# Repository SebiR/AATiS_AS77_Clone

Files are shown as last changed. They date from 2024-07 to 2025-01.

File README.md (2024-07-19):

# AATiS DCF77 Empfänger

This is a clone of the original AATiS AS77 DCF77 Receiver board.

This project was the very first electronic kit that I assembled when I was eleven or twelve years old and it basically started my career as an EE.\
The receiver I built back then still functions to this day and as the design itself celebrates its 30th birthday in this year, I wanted to preserve it for generations to come as the original PCB has been discontinued.

This is a really great project for beginners to learn soldering and learn something about analog circuits and DCF77.



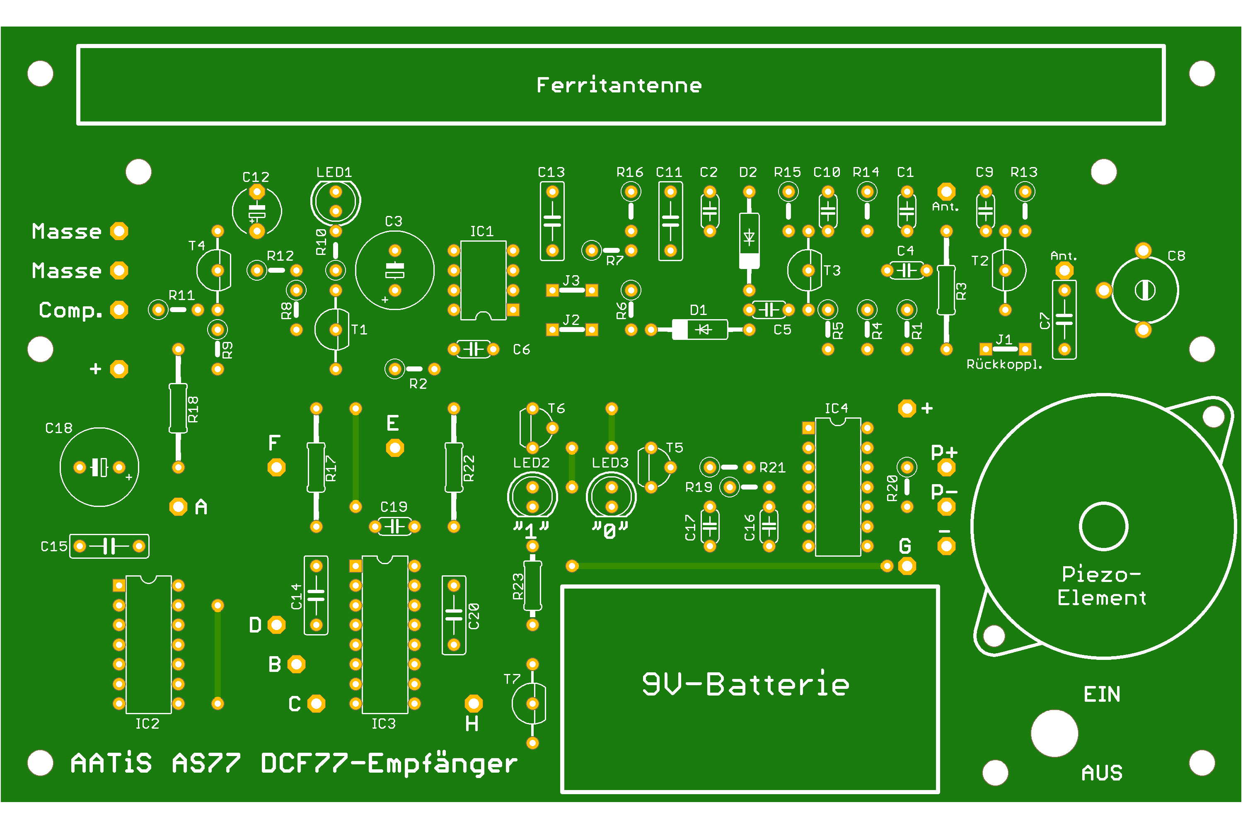
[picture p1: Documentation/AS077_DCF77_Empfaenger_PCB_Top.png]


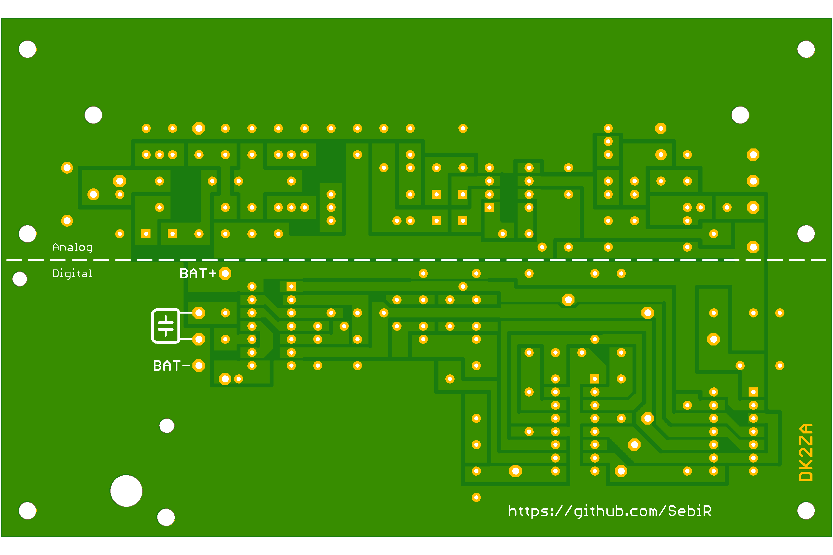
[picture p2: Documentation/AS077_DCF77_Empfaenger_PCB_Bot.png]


## Description

* Mechanical 99.9% identical to the original board
* Layout 99.9% identical to original layout

In case you're wondering: The layout looks a bit strange, but I think it was designed with a really simple CAD software in 1994.
But the layout is great if you want to etch the PCB yourself!

## Status Quo
* Layout basically finished
* Schematic still a mess
* Library needs cleaning up

## Disclaimer
> [!CAUTION]
> This project was created to archive and preserve the DCF77 receiver. AATis/Helmut Pape own all the rights to this design.
> There's no copyright infringement intended, please contact me for removal.

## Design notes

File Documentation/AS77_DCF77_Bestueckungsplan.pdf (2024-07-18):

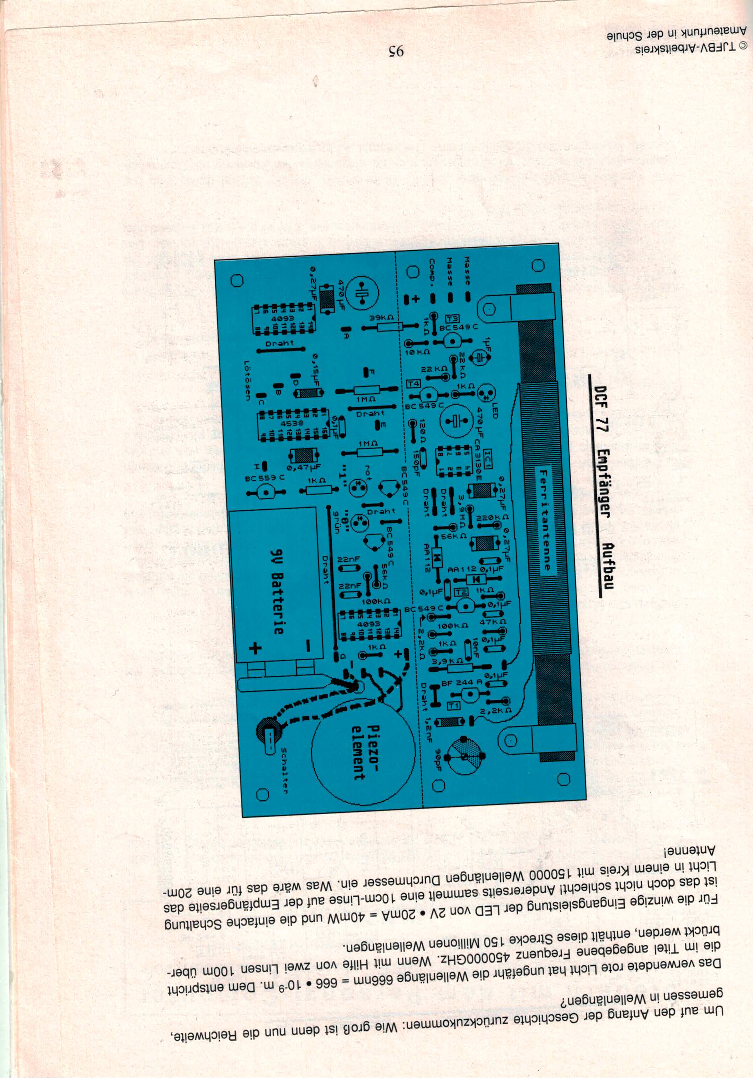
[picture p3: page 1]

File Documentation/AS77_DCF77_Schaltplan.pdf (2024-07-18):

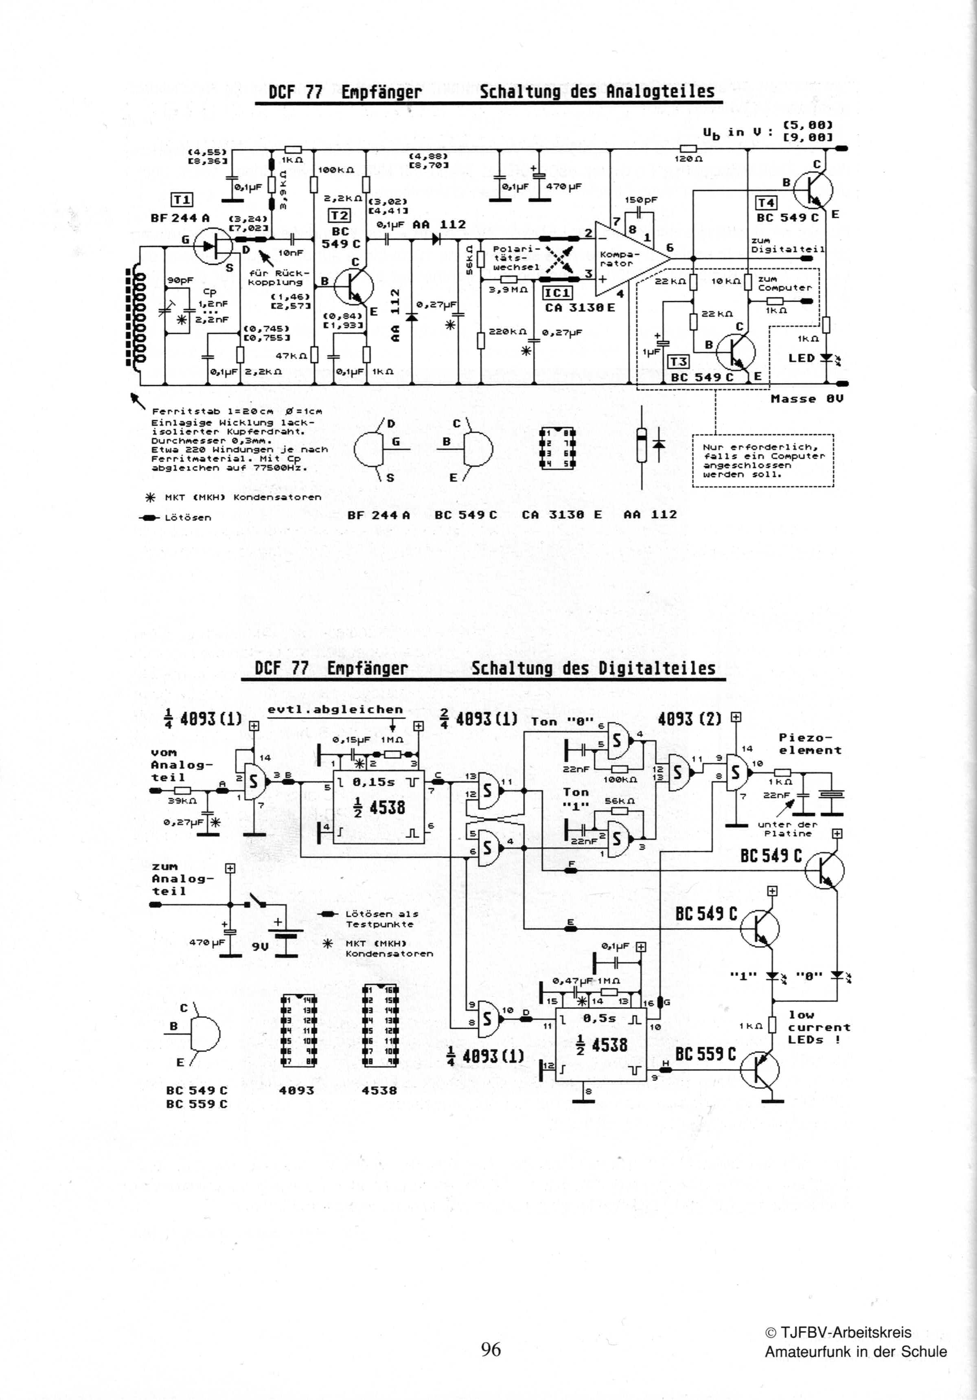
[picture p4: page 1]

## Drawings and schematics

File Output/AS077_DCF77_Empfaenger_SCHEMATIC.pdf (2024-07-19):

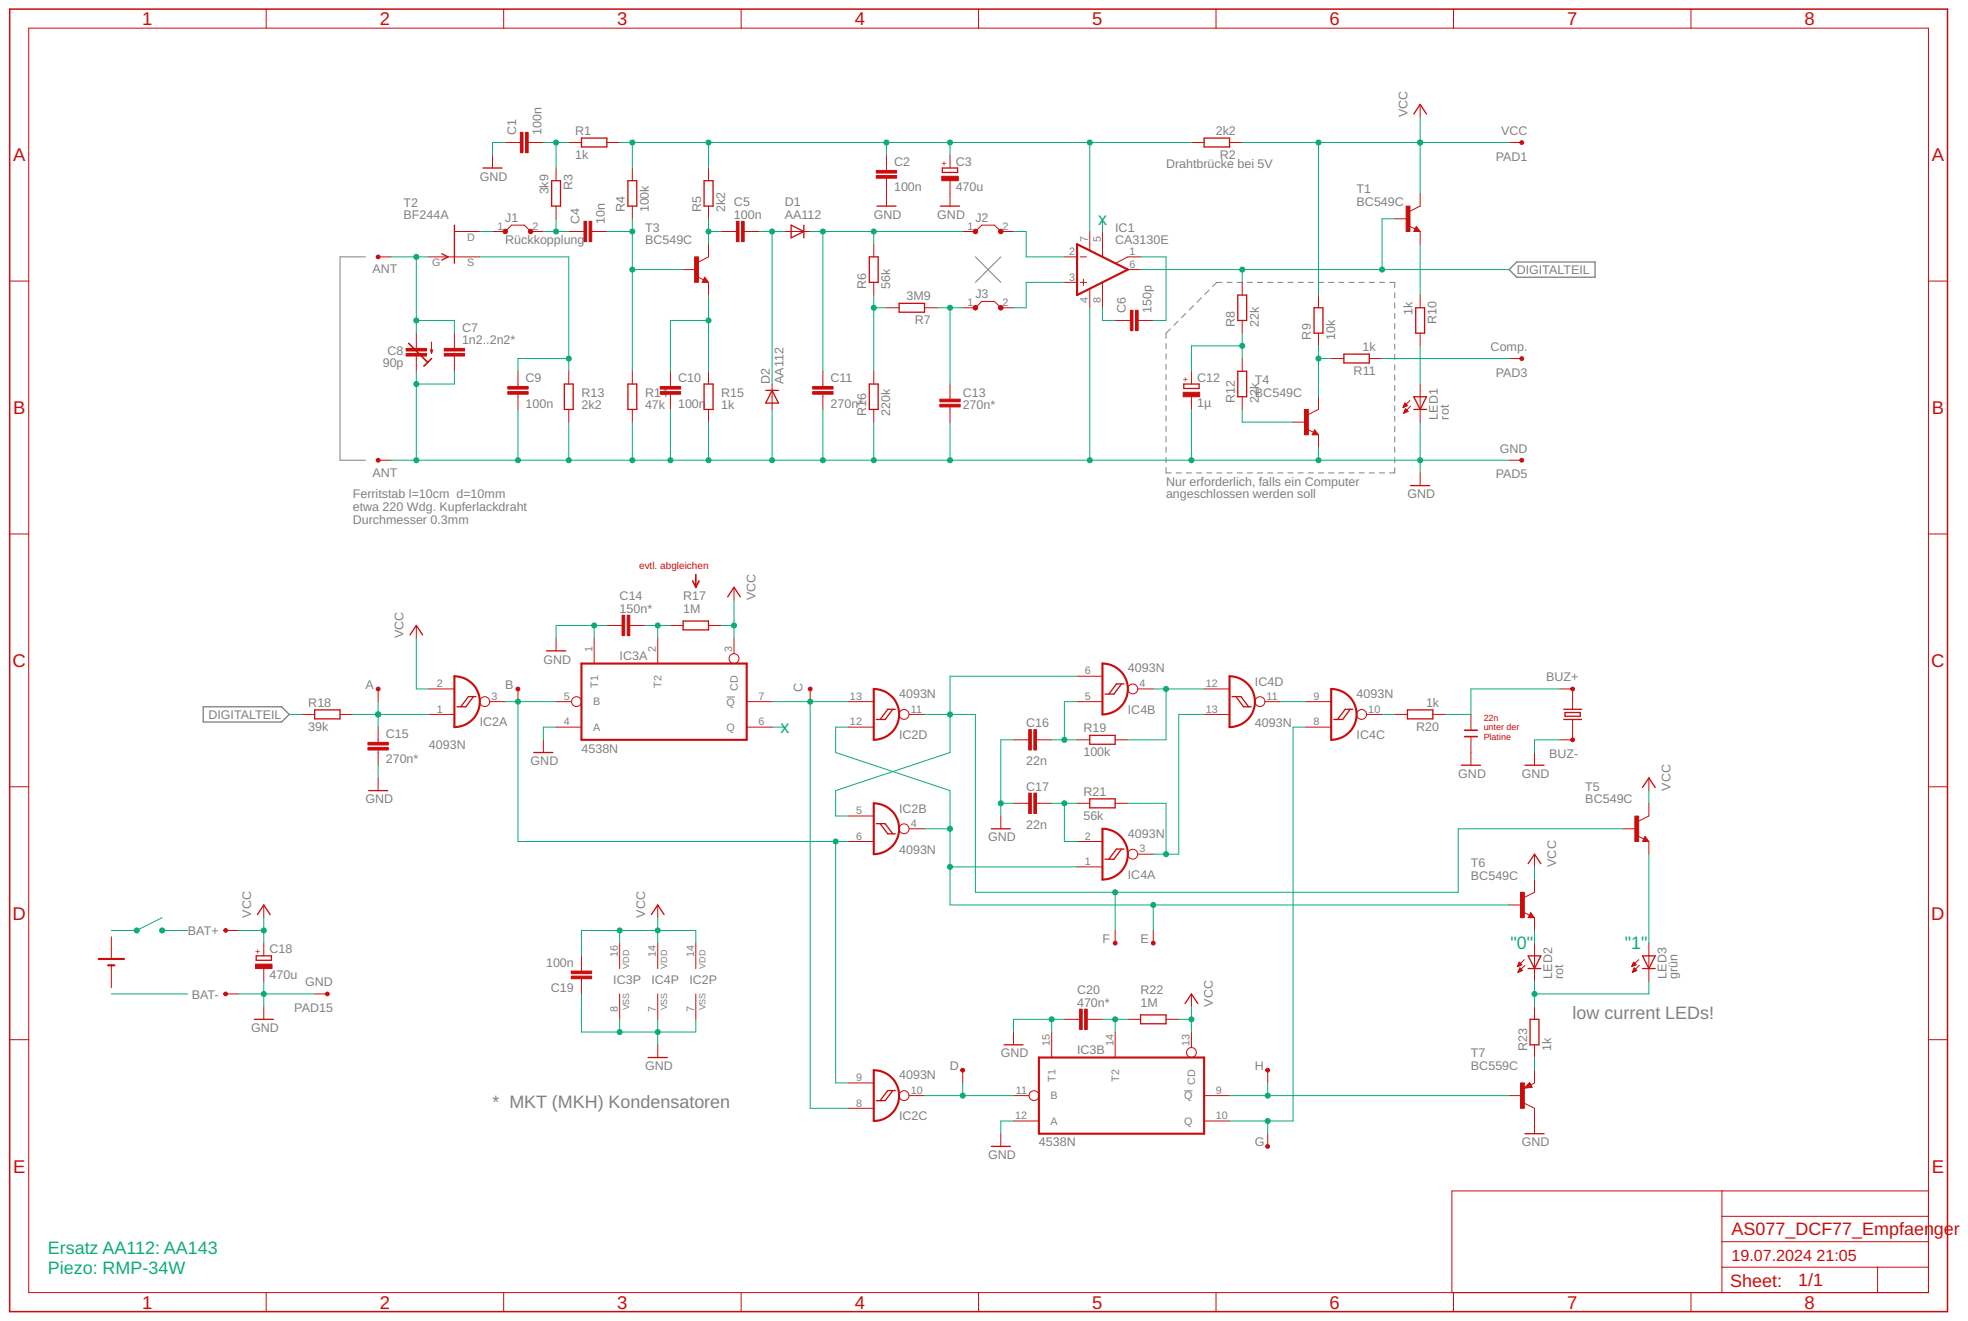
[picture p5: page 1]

ANT
Nur erforderlich, falls ein Computer Ferritstab l=10cm d=10mm

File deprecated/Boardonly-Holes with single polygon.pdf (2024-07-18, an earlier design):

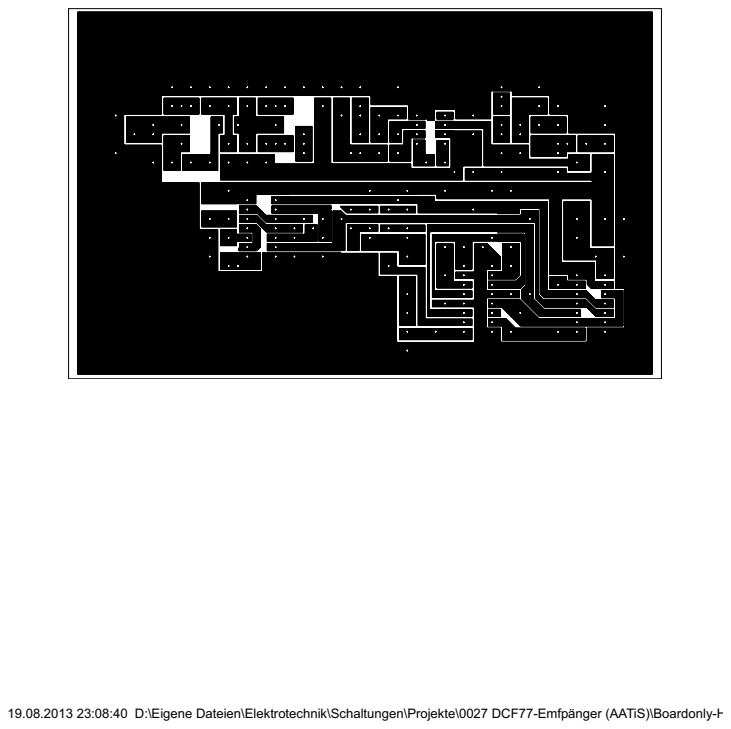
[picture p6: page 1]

19.08.2013 23:08:40 D:\Eigene Dateien\Elektrotechnik\Schaltungen\Projekte\0027 DCF77-Emfpänger (AATiS)\Boardonly-Holes with single polygon.brd

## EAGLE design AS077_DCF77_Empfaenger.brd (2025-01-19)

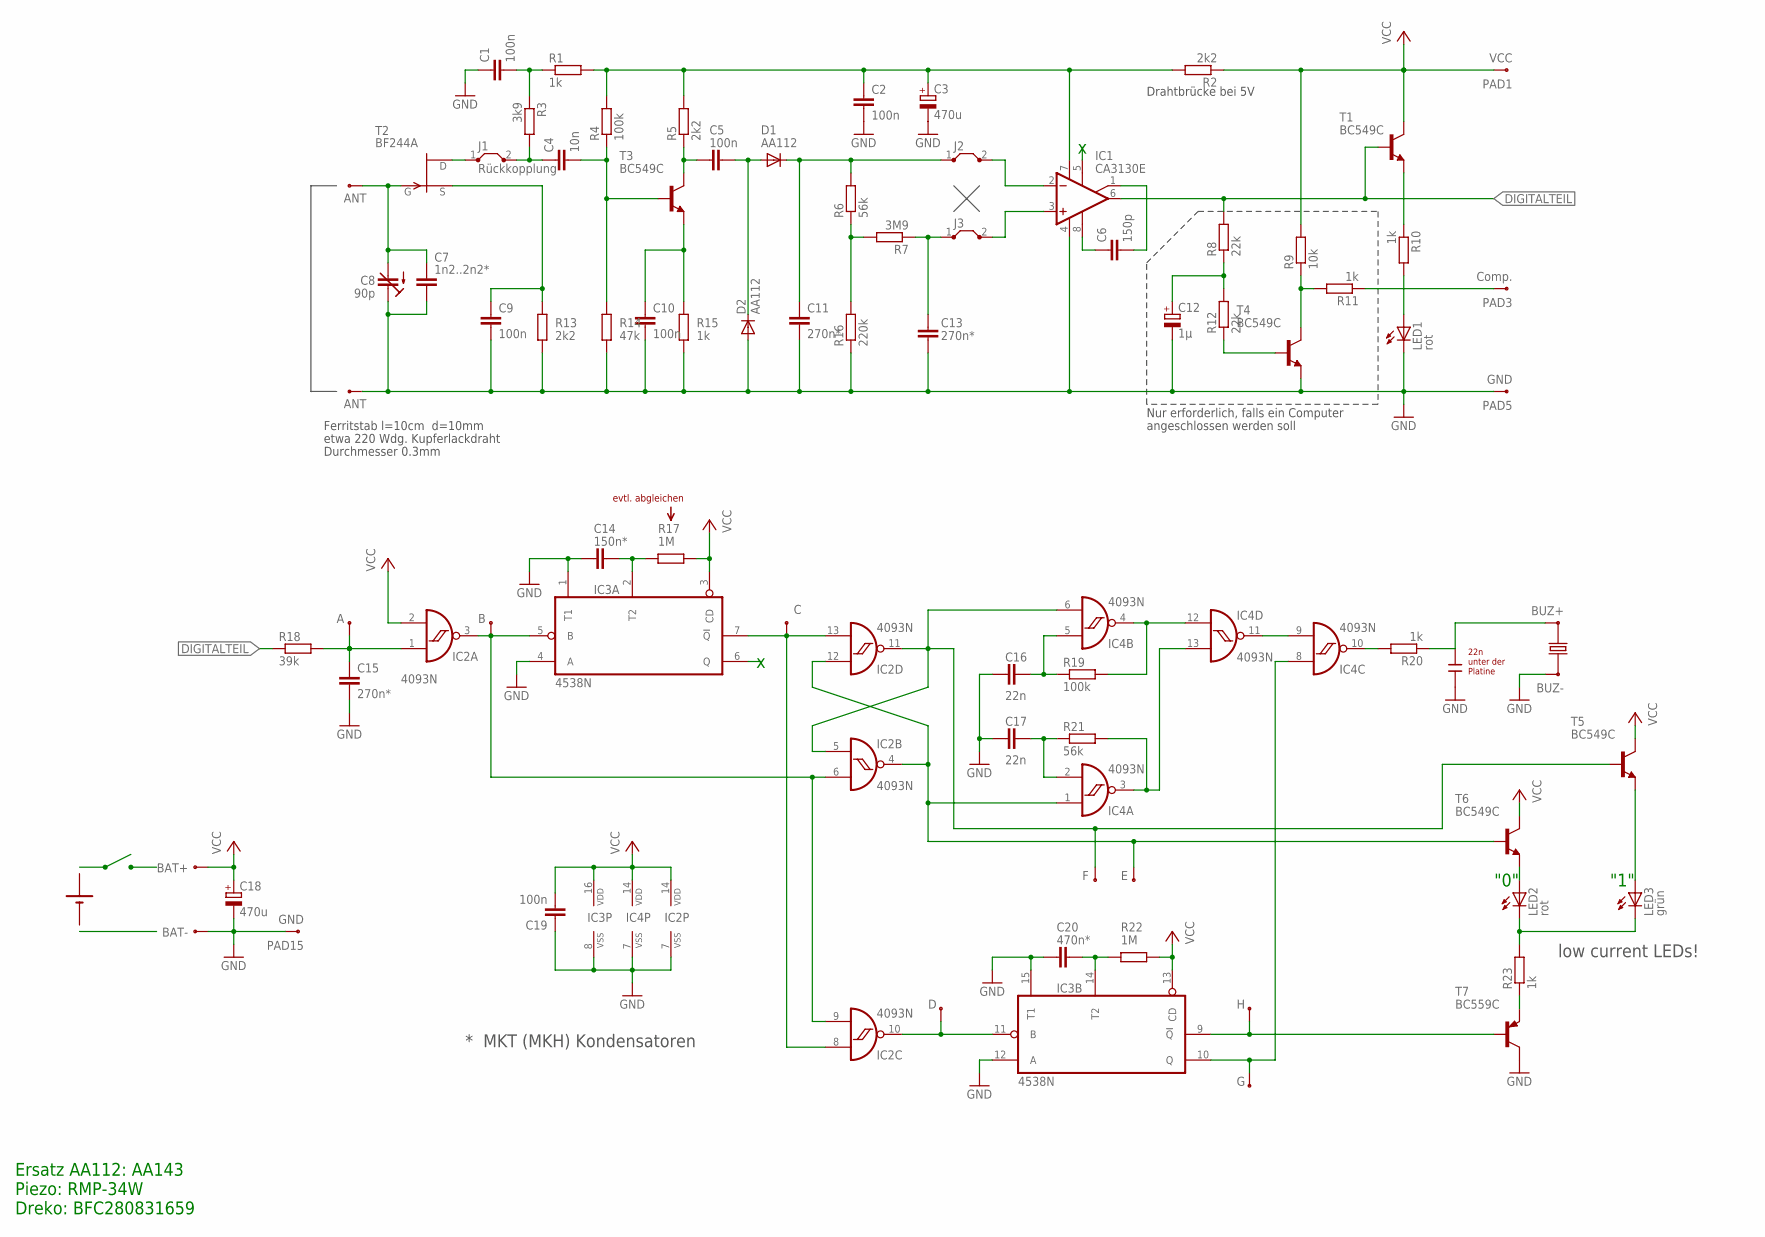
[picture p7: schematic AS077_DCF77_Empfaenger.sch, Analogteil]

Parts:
C1, C2, C5, C9, C10, C19: 100n; RCL_C050-024X044
C3, C18: 470u; RCL_E5-10,5
C4: 10n; RCL_C050-024X044
C6: 150p; RCL_C050-024X044
C7: 1n2..2n2*; RCL_C075-032X103
C8: 90p; RCL_CTRIM808-BC7.5
C11, C13, C15: 270n*; RCL_C075-032X103
C12: 1µ; E5-6
C14: 150n*; RCL_C075-032X103
C16, C17: 22n; RCL_C050-024X044
C20: 470n*; RCL_C075-032X103
D1, D2: AA112; DIODE_DO07
IC1: CA3130E; DIL08
IC2, IC4: 4093N; DIL14
IC3: 4538N; DIL16
J1: Rückkopplung; JUMPER_05
J2, J3: JUMPER_J5MM; JUMPER_05
LED1, LED2: rot; LED_LED5MM
LED3: grün; LED_LED5MM
PAD1: VCC; WIREPAD_2.2/1.3
PAD2, PAD4: ANT; WIREPAD_2.2/1.3
PAD3: Comp.; WIREPAD_2.2/1.3
PAD5, PAD15: GND; WIREPAD_2.2/1.3
PAD6: A; WIREPAD_2.2/1.3
PAD7: B; WIREPAD_2.2/1.3
PAD8: C; WIREPAD_2.2/1.3
PAD9: BUZ-; WIREPAD_2.2/1.3
PAD10: BUZ+; WIREPAD_2.2/1.3
PAD11: BAT+; WIREPAD_2.2/1.3
PAD12: F; WIREPAD_2.2/1.3
PAD13: E; WIREPAD_2.2/1.3
PAD14: BAT-; WIREPAD_2.2/1.3
PAD16: D; WIREPAD_2.2/1.3
PAD17: H; WIREPAD_2.2/1.3
PAD18: G; WIREPAD_2.2/1.3
Q1: 34MM_PIEZO; 34MM_PIEZO_SCREW
R1, R10, R11, R15, R20: 1k; RCL_0207/5V
R2, R5, R13: 2k2; RCL_0207/5V
R3: 3k9; RCL_0207/15
R4, R19: 100k; RCL_0207/5V
R6, R21: 56k; RCL_0207/5V
R7: 3M9; RCL_0207/5V
R8, R12: 22k; RCL_0207/5V
R9: 10k; RCL_0207/5V
R14: 47k; RCL_0207/5V
R16: 220k; RCL_0207/5V
R17, R22: 1M; RCL_0207/15
R18: 39k; RCL_0207/15
R23: 1k; RCL_0207/10
T1, T3, T4: BC549C; TO92_5.08
T2: BF244A; TO92_5.08
T5, T6: BC549C; TO92_2.54
T7: BC559C; TO92_5.08
U$1: 9V_SILKSCREEN; 9V_BLOCK

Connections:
DIGITALTEIL: IC1.6 (OUT), R8.2, R18.1, T1.2 (B)
GND: C1.1, C2.2, C3.-, C7.2, C8.1 (E), C8.3 (E), C9.2, C10.2, C11.2, C12.-, C13.2, C14.1, C15.2, C16.1, C17.1, C18.-, C19.1, C20.1, D2.A, IC1.4 (V-), IC2.7 (VSS), IC3.1 (T1), IC3.4 (A), IC3.8 (VSS), IC3.12 (A), IC3.15 (T1), IC4.7 (VSS), LED1.K (C), PAD4.1, PAD5.1, PAD9.1, PAD14.1, PAD15.1, R13.1, R14.1, R15.1, R16.1, T4.3 (E), T7.1 (C)
unnamed: IC1.3 (+IN), J3.2
unnamed: IC1.2 (-IN), J2.2
unnamed: C13.1, J3.1, R7.1
unnamed: R6.1, R7.2, R16.2
unnamed: C11.1, D1.C, J2.1, R6.2
unnamed: C5.2, D1.A, D2.C
unnamed: C6.1, IC1.8 (CMP)
unnamed: C10.1, R15.2, T3.3 (E)
unnamed: C5.1, R5.1, T3.1 (C)
unnamed: C4.2, R4.1, R14.2, T3.2 (B)
unnamed: C2.1, C3.+, IC1.7 (V+), R1.2, R2.2, R4.2, R5.2
unnamed: C1.2, R1.1, R3.1
unnamed: C4.1, J1.2, R3.2
unnamed: J1.1, T2.3 (D)
unnamed: C9.1, R13.2, T2.1 (S)
unnamed: C6.2, IC1.1 (ON/CMP)
unnamed: PAD10.1, R20.1
unnamed: C7.1, C8.2 (A), PAD2.1, T2.2 (G)
unnamed: C20.2, IC3.14 (T2), R22.2
unnamed: C12.+, R8.1, R12.2
unnamed: PAD3.1, R11.1
unnamed: R12.1, T4.2 (B)
unnamed: R9.1, R11.2, T4.1 (C)
unnamed: LED1.A, R10.2
unnamed: R10.1, T1.3 (E)
unnamed: C15.1, IC2.1 (I0), PAD6.1, R18.2
unnamed: IC2.8 (I0), IC2.13 (I1), IC3.7 (!Q), PAD8.1
unnamed: IC2.5 (I0), IC2.11 (O), IC4.6 (I1), PAD12.1, T5.2 (B)
unnamed: IC4.4 (O), IC4.12 (I0), R19.2
unnamed: IC2.3 (O), IC2.6 (I1), IC2.9 (I1), IC3.5 (B), PAD7.1
unnamed: IC2.10 (O), IC3.11 (B), PAD16.1
unnamed: IC2.4 (O), IC2.12 (I0), IC4.1 (I0), PAD13.1, T6.2 (B)
unnamed: IC4.3 (O), IC4.13 (I1), R21.2
unnamed: IC4.9 (I1), IC4.11 (O)
unnamed: C16.2, IC4.5 (I0), R19.1
unnamed: C17.2, IC4.2 (I1), R21.1
unnamed: C14.2, IC3.2 (T2), R17.2
unnamed: IC3.10 (Q), IC4.8 (I0), PAD18.1
unnamed: IC3.9 (!Q), PAD17.1, T7.2 (B)
unnamed: R23.1, T7.3 (E)
unnamed: LED2.A, T6.3 (E)
unnamed: LED3.A, T5.3 (E)
unnamed: LED2.K (C), LED3.K (C), R23.2
unnamed: IC4.10 (O), R20.2
VCC: C18.+, C19.2, IC2.2 (I1), IC2.14 (VDD), IC3.3 (CD), IC3.13 (CD), IC3.16 (VDD), IC4.14 (VDD), PAD1.1, PAD11.1, R2.1, R9.2, R17.1, R22.1, T1.1 (C), T5.1 (C), T6.1 (C)

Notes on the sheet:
angeschlossen werden soll
Nur erforderlich, falls ein Computer
Ferritstab l=10cm d=10mm
etwa 220 Wdg. Kupferlackdraht
Durchmesser 0.3mm
Drahtbrücke bei 5V
Ersatz AA112: AA143 Piezo: RMP-34W Dreko: BFC280831659
"0"
"1"
* MKT (MKH) Kondensatoren
low current LEDs!
22n unter der Platine
evtl. abgleichen

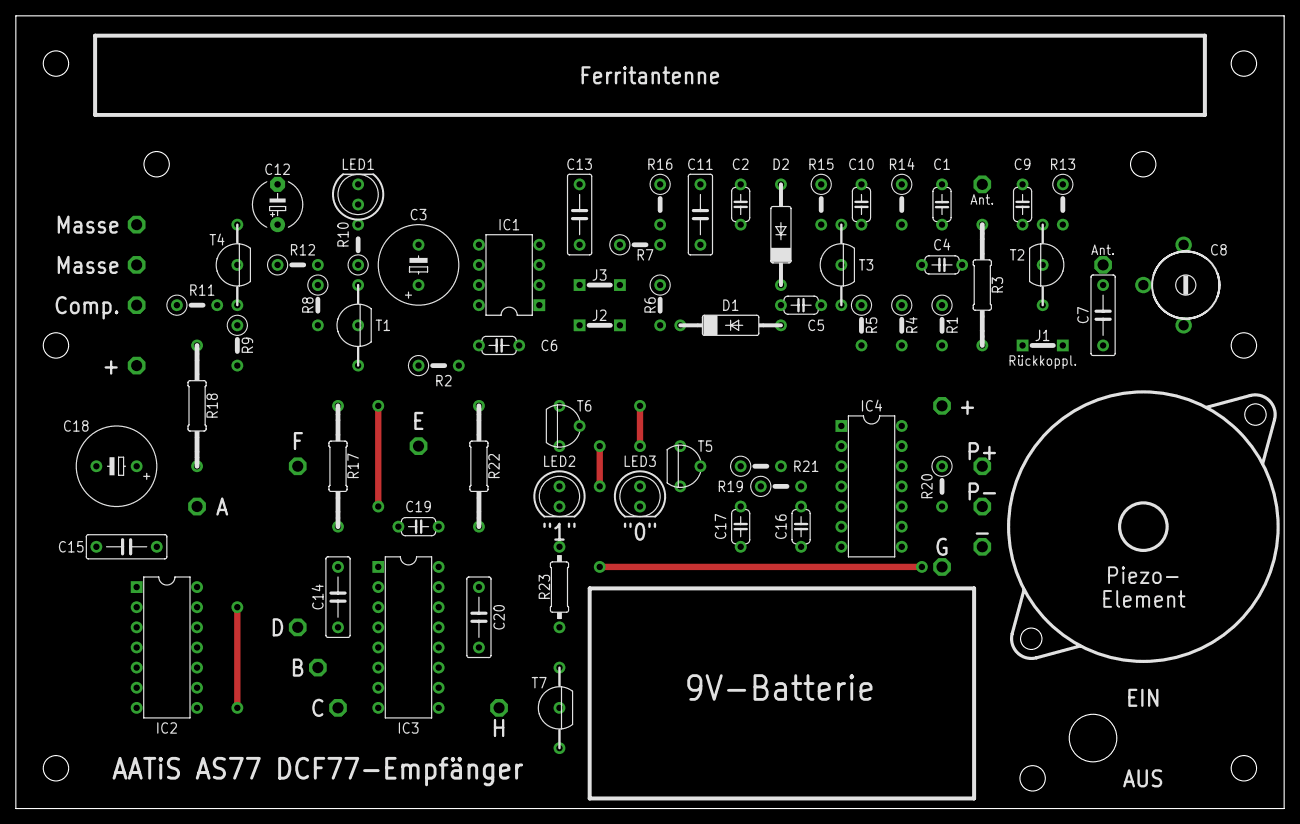
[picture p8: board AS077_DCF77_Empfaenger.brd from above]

Board: 2 copper layers, 160.0 x 100.0 mm, 82 parts (0 on the bottom side), 47 nets.

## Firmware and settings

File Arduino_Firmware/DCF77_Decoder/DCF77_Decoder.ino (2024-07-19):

#define STATUS_PIN LED_BUILTIN
#define DCF_PIN 2

int HIGH_Start = 0;
int HIGH_Ende = 0;
int HIGH_Zeit = 0;
int LOW_Start = 0;
int LOW_Ende = 0;
int LOW_Zeit = 0;

bool Signal = false;
bool neueMinute = false;
int BIT = -1;
int ZEIT[65];
int ZEIT_STUNDE;
int ZEIT_MINUTE;
int ZEIT_TAG;
int ZEIT_MONAT;
int ZEIT_JAHR;
int ZEIT_WOCHENTAG;
int PAR_STUNDE;
int PAR_MINUTE;
int PAR_BEGINN;

void setup() {
  Serial.begin(115200);
  pinMode(DCF_PIN, INPUT);
  pinMode(STATUS_PIN, OUTPUT);
  Serial.println("Syncronisierung");
}

void loop() {
  if (BIT > 60) { neueMinute = false; }
  int DCF_SIGNAL = digitalRead(DCF_PIN);

  if (DCF_SIGNAL == LOW && Signal == false) {
    Signal = true;
    HIGH_Start = millis();
    LOW_Ende = HIGH_Start;
    LOW_Zeit = LOW_Ende - LOW_Start;

    if (neueMinute == true) {
      PrintBeschreibung(BIT);
      //Serial.print("Bit");
      //Serial.print (BIT);
      //Serial.print (": ");
      ZEIT[BIT] = (BIT_Zeit(LOW_Zeit));
      Serial.print(ZEIT[BIT]);
      //Serial.println ();
    } else {
      Serial.print(".");
    }
  }

  if (DCF_SIGNAL == HIGH && Signal == true) {
    Signal = false;
    HIGH_Ende = millis();
    LOW_Start = HIGH_Ende;
    HIGH_Zeit = HIGH_Ende - HIGH_Start;

    NEUMINUTE(LOW_Zeit);
  }
}

int BIT_Zeit(int LOW_Zeit) {
  if (LOW_Zeit >= 851 && LOW_Zeit <= 950) { return 0; }
  if (LOW_Zeit >= 750 && LOW_Zeit <= 850) { return 1; }
  if (LOW_Zeit <= 350) {
    BIT -= 1;
    return "";
  }
}

void NEUMINUTE(int LOW_Zeit) {
  if (LOW_Zeit >= 1700) {
    BIT = 0;
    neueMinute = true;
    ZEIT_STUNDE = ZEIT[29] * 1 + ZEIT[30] * 2 + ZEIT[31] * 4 + ZEIT[32] * 8 + ZEIT[33] * 10 + ZEIT[34] * 20;
    ZEIT_MINUTE = ZEIT[21] * 1 + ZEIT[22] * 2 + ZEIT[23] * 4 + ZEIT[24] * 8 + ZEIT[25] * 10 + ZEIT[26] * 20 + ZEIT[27] * 40;
    PAR_STUNDE = ZEIT[35];
    PAR_MINUTE = ZEIT[28];
    ZEIT_TAG = ZEIT[36] * 1 + ZEIT[37] * 2 + ZEIT[38] * 4 + ZEIT[39] * 8 + ZEIT[40] * 10 + ZEIT[41] * 20;
    ZEIT_MONAT = ZEIT[45] * 1 + ZEIT[46] * 2 + ZEIT[47] * 4 + ZEIT[48] * 8 + ZEIT[49] * 10;
    ZEIT_JAHR = 2000 + ZEIT[50] * 1 + ZEIT[51] * 2 + ZEIT[52] * 4 + ZEIT[53] * 8 + ZEIT[54] * 10 + ZEIT[55] * 20 + ZEIT[56] * 40 + ZEIT[57] * 80;
    PAR_BEGINN = ZEIT[20];



    Serial.println();
    Serial.println("*****************************");
    Serial.print("Uhrzeit: ");
    Serial.println();
    Serial.print(ZEIT_STUNDE);
    Serial.print(":");
    Serial.print(ZEIT_MINUTE);
    Serial.println();
    Serial.println();
    Serial.print("Datum: ");
    Serial.println();
    Serial.print(ZEIT_TAG);
    Serial.print(".");
    Serial.print(ZEIT_MONAT);
    Serial.print(".");
    Serial.print(ZEIT_JAHR);
    Serial.println();
    Serial.println("*****************************");


  } else {
    BIT++;
  }
}

void PrintBeschreibung(int BitNummer) {
  switch (BitNummer) {
    case 0: Serial.println("\n# START MINUTE (IMMER 0)"); break;
    case 1: Serial.println("\n# WETTERDATEN"); break;
    case 15: Serial.println("\n# RUFBIT"); break;
    case 16: Serial.println("\n# MEZ/MESZ"); break;
    case 17: Serial.println("\n# MESZ"); break;
    case 18: Serial.println("\n# MEZ"); break;
    case 19: Serial.println("\n# SCHALTSEKUNDE"); break;
    case 20: Serial.println("\n# BEGIN ZEITINFORMATION (IMMER 1)"); break;
    case 21: Serial.println("\n# MINUTEN"); break;
    case 28: Serial.println("\n# PARITAET MINUTE"); break;
    case 29: Serial.println("\n# STUNDE"); break;
    case 35: Serial.println("\n# PARITAET STUNDE"); break;
    case 36: Serial.println("\n# TAG"); break;
    case 42: Serial.println("\n# WOCHENTAG"); break;
    case 45: Serial.println("\n# MONAT"); break;
    case 50: Serial.println("\n# JAHR"); break;
    case 58: Serial.println("\n# PARITAET DATUM"); break;
  }
}

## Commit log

2024-07-18 * Added "bottom capacitor" * Added nets and polygons to not connected IC pins
    [AS077_DCF77_Empfaenger.brd, AS077_DCF77_Empfaenger.sch]
2024-07-18 * Added more details to the silkscreen * Fixed all Values in schematic
    [AS077_DCF77_Empfaenger.brd, AS077_DCF77_Empfaenger.sch]
2024-07-18 * Updated PCB renderings
2024-07-18 * more silkscreen improvements * added GERBER
    [AS077_DCF77_Empfaenger.brd, AS077_DCF77_Empfaenger.sch]
2024-07-19 * Updated and cleaned up the library * Cleaned up the schematic * Renumbered all parts * Updated images, gerbers and schematic pdf * Added small arduino test script for decoding
    [AS077_DCF77_Empfaenger.brd, AS077_DCF77_Empfaenger.sch]
2024-07-19 Change some components
    [AS077_DCF77_Empfaenger.brd, AS077_DCF77_Empfaenger.sch]
2024-07-19 * Renamed included library * Changed all references to new lib name
    [AS077_DCF77_Empfaenger.brd, AS077_DCF77_Empfaenger.sch]
2024-07-19 * More schematic and layout cleanup
    [AS077_DCF77_Empfaenger.brd, AS077_DCF77_Empfaenger.sch]
2024-07-19 Minor Fixes
    [AS077_DCF77_Empfaenger.brd, AS077_DCF77_Empfaenger.sch]
2024-12-26 updated LBR and BRD: Solder pin holes are now 1.4mm drills instead of 1.3
    [AS077_DCF77_Empfaenger.brd, AS077_DCF77_Empfaenger.sch, Boardonly-Holes with single polygon.brd]
2025-01-19 * Updated test pin hole diameter also in BRD and GERBER (only updated LBR before)
    [AS077_DCF77_Empfaenger.brd, AS077_DCF77_Empfaenger.sch]
